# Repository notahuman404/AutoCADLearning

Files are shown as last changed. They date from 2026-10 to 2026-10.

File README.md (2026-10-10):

# Starbie

Starbie is a small motion-controlled digital pet built around a Seeed Studio XIAO ESP32-C3. It draws a one-bit pet on a 128×64 OLED, uses an MPU6050 to read tilt and shaking, and offers a four-way action menu. A DHT11 can provide temperature and humidity readings.

## Project images

<table>
  <tr>
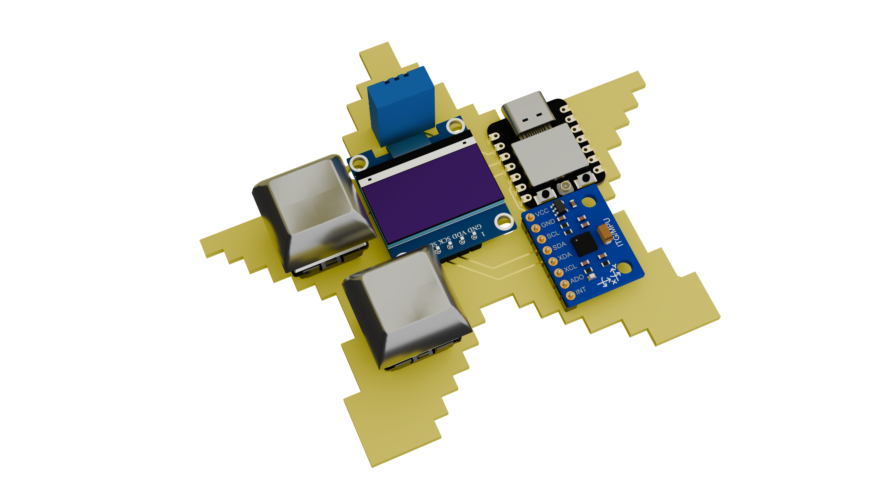
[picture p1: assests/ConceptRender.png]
Starbie concept render
    <td align="center"><strong>Concept render</strong><br></td>
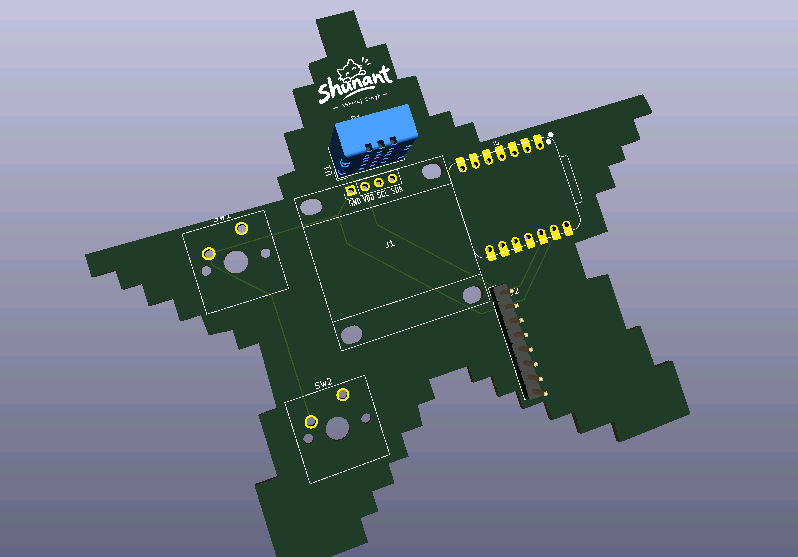
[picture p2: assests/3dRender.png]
Starbie PCB 3D render
    <td align="center"><strong>3D PCB render</strong><br></td>
  </tr>
  <tr>
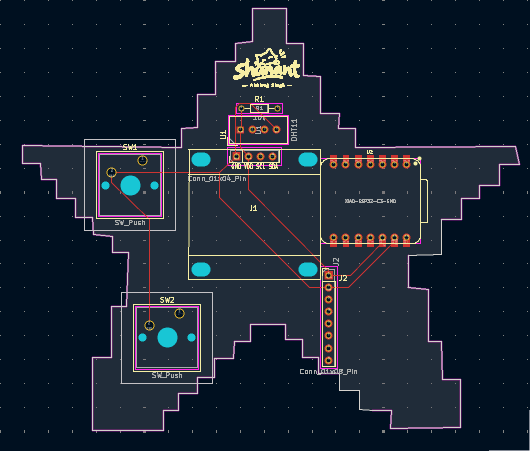
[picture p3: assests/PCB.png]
KiCad PCB layout
    <td align="center"><strong>PCB layout</strong><br></td>
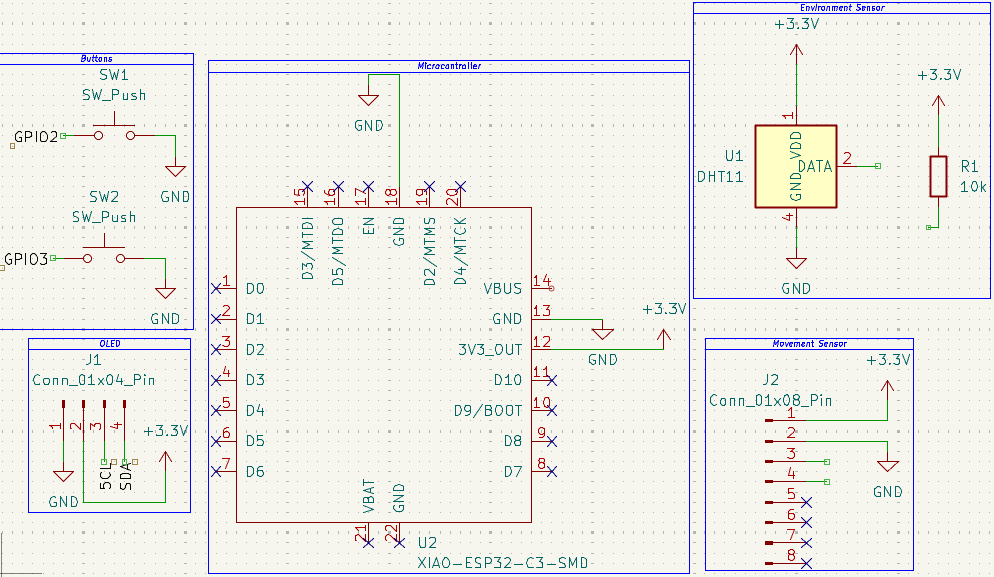
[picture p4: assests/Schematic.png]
KiCad schematic
    <td align="center"><strong>Schematic</strong><br></td>
  </tr>
</table>

## Features

- Animated pet with nap, play, feed, and pet actions.
- Tilt-controlled radial menu, using the MPU6050 as a simple air mouse.
- Shake reaction that wakes Starbie and changes its stats.
- Stats screen for joy, energy, fullness, and available sensor readings.
- Joy, energy, and fullness are saved using the ESP32 Preferences storage; stats do not drain while idle.

## Hardware

| Part | Role |
| --- | --- |
| Seeed Studio XIAO ESP32-C3 | Controller and firmware target |
| 0.96-inch 128×64 I²C OLED, SSD1306-compatible | Pet display |
| MPU6050 module (external via J2) | Tilt and shake sensing |
| DHT11 | Optional temperature and humidity sensing |
| 2 Cherry MX-compatible 1U switches | Menu/action and stats controls |
| 10 kΩ through-hole resistor | Listed as R1 in the schematic |
| Custom PCB | KiCad design in the starbie directory |

See BOM.csv for the current parts list. The guide pairs the XIAO ESP32-C3 symbol with the custom footprint ID `Imported Parts:XIAO-ESP32-C6-DIP`; the BOM preserves that assignment. The guide represents the MPU6050 module with a generic 1x08 connector: J2 is the board-mounted header and pins 1-4 carry +3.3V, GND, SCL, and SDA. The guide does not specify a particular breakout-board variant, so the BOM names it as an MPU6050 module connected via J2.

## Wiring

The firmware pin assignments are in Firmware/Starbie/Starbie.ino. OLED and MPU6050 share I²C.

| Device | XIAO connection | Notes |
| --- | --- | --- |
| OLED SDA | D4 / GPIO6 | I²C address defaults to 0x3C |
| OLED SCL | D5 / GPIO7 | Shared I²C bus |
| MPU6050 SDA | D4 / GPIO6 | I²C address defaults to 0x68 |
| MPU6050 SCL | D5 / GPIO7 | Shared I²C bus |
| DHT11 data | D1 / GPIO3 | Optional; set USE_DHT11 to false if not fitted |
| Button 1 | D2 / GPIO4 | Opens the menu; confirms the selected action |
| Button 2 | D3 / GPIO5 | Shows or hides the stats screen |

Connect module power and ground according to the module labels and the schematic. Verify voltage and pin order before powering the board.

## Firmware setup

1. Install Arduino IDE and add the Espressif ESP32 board package URL: https://espressif.github.io/arduino-esp32/package_esp32_index.json
2. Install the ESP32 board package by Espressif Systems and select XIAO_ESP32C3 under Tools → Board → esp32.
3. Install Adafruit GFX Library, Adafruit SSD1306, Adafruit MPU6050, and DHT sensor library. Accept the IDE's dependency prompts.
4. Open Firmware/Starbie/Starbie.ino, check the beginner settings and pin assignments, then upload to the XIAO ESP32-C3.

Button 1 opens the four-way menu. Tilt toward top for NAP, right for PLAY, bottom for FEED, or left for PET; press Button 1 again to confirm. Button 2 toggles stats. Shaking Starbie gives it a reaction and wakes it from a nap. The DHT11 can be disabled with USE_DHT11 if that sensor is not installed.

## Repository layout

- Firmware/Starbie/Starbie.ino — Arduino firmware.
- starbie/ — KiCad schematic, board, and project files.
- assests/ — project renders, schematic, and PCB images (the directory name is intentionally kept as it exists in the repository).
- 3D Models/ — STEP models for the display, switches, sensor module, and controller.
- Imported Parts.pretty/ — custom KiCad footprints.

## Reference

This project follows the [Starbie Week 1 guide](https://github.com/SharKingStudios/Starbie/blob/main/Week%201%20Guide.md).

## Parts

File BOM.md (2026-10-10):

# Starbie – bill of materials

<!-- Generated by Half Life from project cmuv3oycx0d7t01smc6fq98m5. Edits here are overwritten on the next sync. -->
<!-- Generated: 2026-10-10T05:16:34.077Z -->

> [!NOTE]
> This parts list is mirrored from [Half Life](https://halflife.hackclub.com). Editing it here will not change the platform's copy, and the next sync overwrites this file.

| Week | Tier | Parts funding |
| --- | --- | --- |
| Week 1 | Tier 1 | $30.00 |

| Part | What it's for | Qty | Unit | Total | Vendor |
| --- | --- | --- | --- | --- | --- |
| [Seeed Studio XIAO ESP32-C3](https://www.seeedstudio.com/Seeed-XIAO-ESP32C3-p-5431.html) | Main controller; firmware target | 1 | $4.90 | $4.90 | [Seeed Studio](https://www.seeedstudio.com/Seeed-XIAO-ESP32C3-p-5431.html) |
| [0.96-inch 128×64 SSD1306-compatible I²C OLED module](https://www.displaymodule.com/products/0-96-inch-oled-graphic-display-128x64-with-spi-i2c) | Displays the pet and menus | 1 | $4.90 | $4.90 | [DisplayModule](https://www.displaymodule.com/products/0-96-inch-oled-graphic-display-128x64-with-spi-i2c) |
| [DHT11 temperature/humidity sensor](https://shop.kincony.com/products/dht11-temperature-and-humidity-sensor) | temperature and humidity readings | 1 | $3.00 | $3.00 | [KinCony](https://shop.kincony.com/products/dht11-temperature-and-humidity-sensor) |
| [1×8, 2.54 mm vertical pin header](https://in.element14.com/molex/22-29-2081/conn-pin-hdr-8pos-1row-2-54mm/dp/1360136) | Board connector for the external motion-sensor module | 1 | $0.99 | $0.99 | [element14](https://in.element14.com/molex/22-29-2081/conn-pin-hdr-8pos-1row-2-54mm/dp/1360136) |
| [MX1A-51NN](https://www.mouser.in/en/ProductDetail/CHERRY/MX1A-51NN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) | Two user buttons | 2 | $1.23 | $2.46 | [Mouser](https://www.mouser.in/en/ProductDetail/CHERRY/MX1A-51NN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) |
| [MPU6050-6 Axis](https://rajivelectronics.com/product/mpu6050-triple-axis-gyro-accelerometer-module) | Tilt and shake sensing | 1 | $1.88 | $1.88 | [Rajiv Electronics](https://rajivelectronics.com/product/mpu6050-triple-axis-gyro-accelerometer-module) |
| [10 kΩ through-hole resistor](https://www.tanotis.com/products/genuine-sparkfun-resistor-10k-ohm-1-6th-watt-pth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) | it holds the data signal high when the sensor isn’t pulling it low | 1 | $0.15 | $0.15 | [Tanotis](https://www.tanotis.com/products/genuine-sparkfun-resistor-10k-ohm-1-6th-watt-pth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) |
| **Parts subtotal** | — | — | — | **$18.28** | — |
| **Tax & shipping** | — | — | — | **$0.00** | — |
| **Total** | — | — | — | **$18.28** | — |

$11.72 left of the tier's funding.

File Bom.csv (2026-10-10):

Reference | Quantity | Value | Footprint | Description
J1 | 1 | Conn_01x04_Pin | Imported Parts:Display_128x64_096_I2C | 0.96-inch 128x64 I2C OLED interface; firmware expects an SSD1306-compatible module
J2 | 1 | Conn_01x08_Pin | Connector_PinHeader_2.54mm:PinHeader_1x08_P2.54mm_Vertical | 1x8 2.54 mm vertical pin header
R1 | 1 | 10k | Resistor_THT:R_Axial_DIN0204_L3.6mm_D1.6mm_P7.62mm_Horizontal | 10 kΩ through-hole resistor
SW1 | 1 | SW_Push | Button_Switch_Keyboard:SW_Cherry_MX_1.00u_PCB | Cherry MX-compatible 1U momentary switch
SW2 | 1 | SW_Push | Button_Switch_Keyboard:SW_Cherry_MX_1.00u_PCB | Cherry MX-compatible 1U momentary switch
U1 | 1 | DHT11 | Sensor:Aosong_DHT11_5.5x12.0_P2.54mm | DHT11 temperature/humidity sensor
U2 | 1 | XIAO-ESP32-C3-SMD | Imported Parts:XIAO-ESP32-C6-DIP | Seeed Studio XIAO ESP32-C3 controller module
MPU6050 | 1 | MPU6050 | External module; connects through J2 (1x08) | Six-axis accelerometer/gyroscope module for tilt and shake sensing
PCB1 | 1 | Custom PCB | N/A (bare PCB) | Bare PCB fabricated from current KiCad board; Gerber files: Gerber-Files.zip

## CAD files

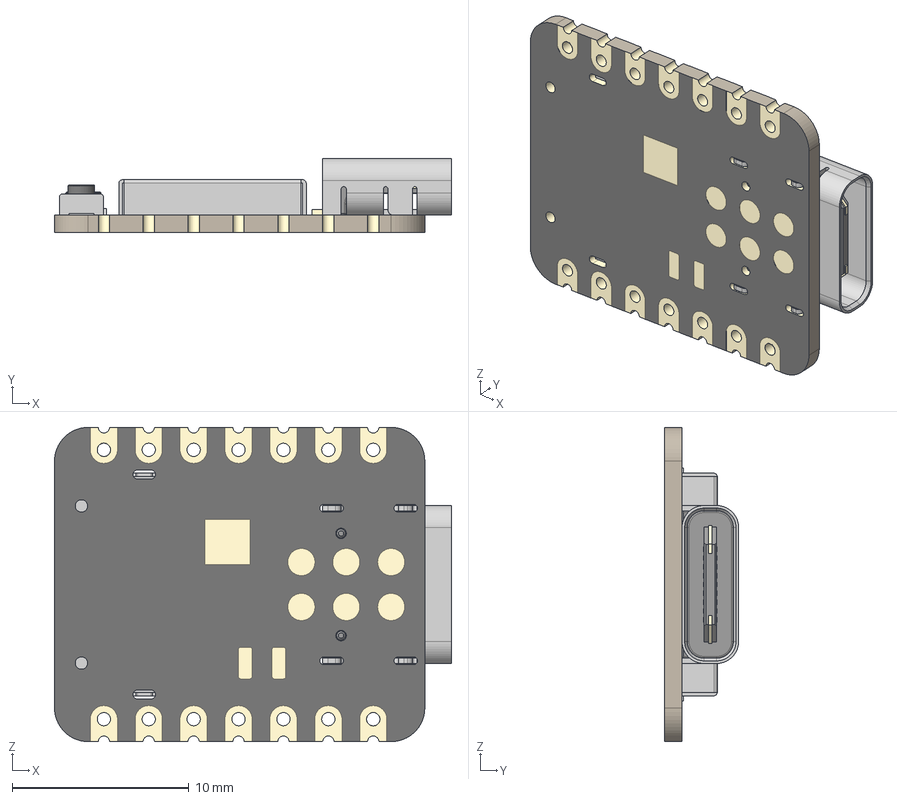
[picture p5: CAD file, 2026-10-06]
3D Models/Seeed Studio XIAO-ESP32-C3.step
22.5 x 4.21 x 17.8 mm
BOSS-EXTRUDE14_8_
BOSS-EXTRUDE7_4_
BOSS-EXTRUDE7_3_
BOSS-EXTRUDE14_4_
BOSS-EXTRUDE14_2_
BOSS-EXTRUDE14_11_
BOSS-EXTRUDE7_7_
BOSS-EXTRUDE14_9_
BOSS-EXTRUDE14_3_
BOSS-EXTRUDE14_7_
MIRROR2
BOSS-EXTRUDE14_5_
BOSS-EXTRUDE14_12_
BOSS-EXTRUDE7_8_
BOSS-EXTRUDE7_1_
BOSS-EXTRUDE14_10_
BOSS-EXTRUDE7_9_
BOSS-EXTRUDE14_6_
BOSS-EXTRUDE14_1_
BOSS-EXTRUDE7_6_
BOSS-EXTRUDE7_2_
CUT-EXTRUDE5
BOSS-EXTRUDE7_5_
U.FL Connector v1
Button (1) x 2
Shield

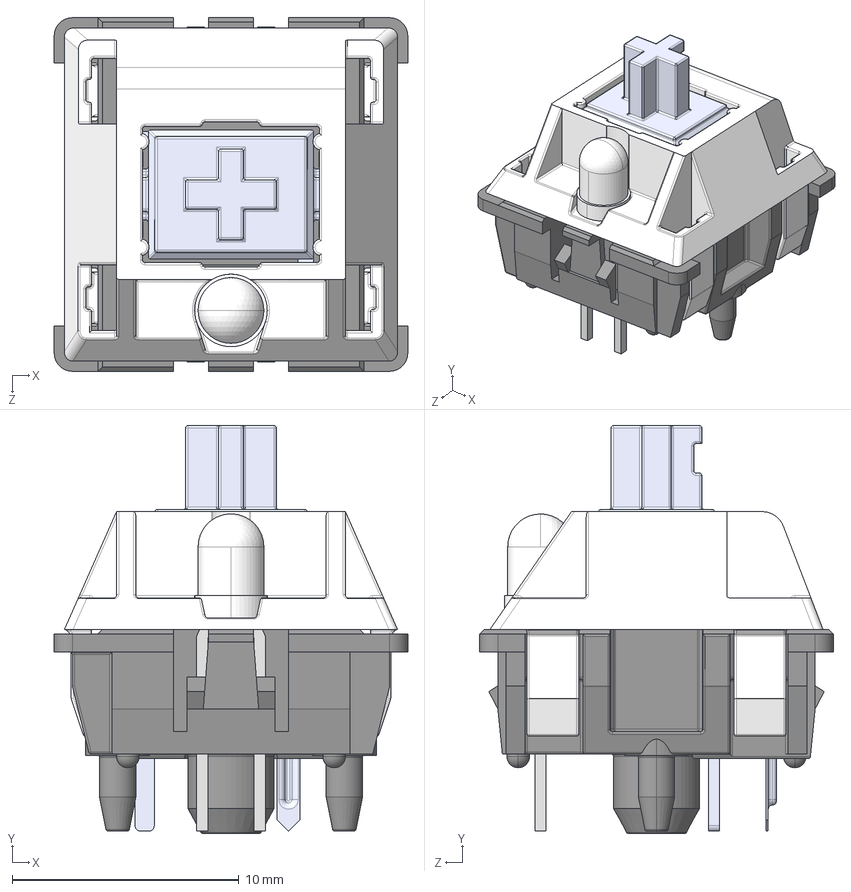
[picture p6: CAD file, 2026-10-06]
3D Models/Cherry MX.STEP
15.6 x 18.0 x 15.6 mm
Bottom
Pulsador
Top
Pieza5^Cherry MX
Pin1
Pin2
Led 3mm_trans

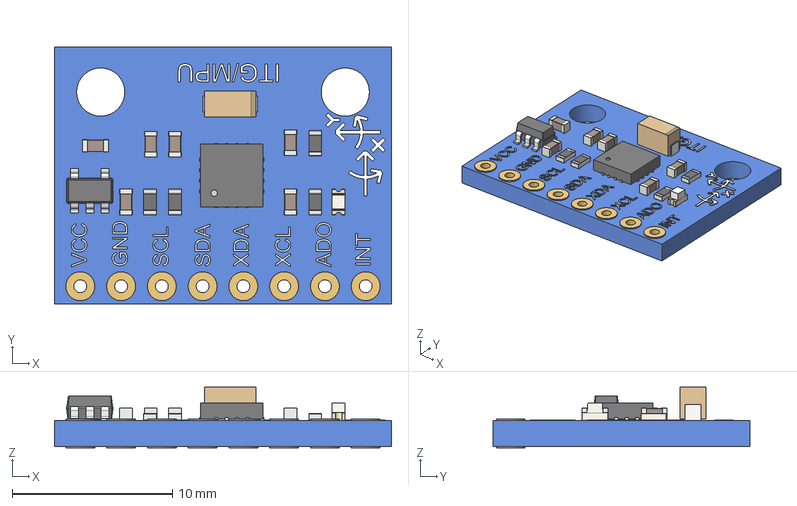
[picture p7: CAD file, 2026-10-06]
3D Models/GY-521_MPU6050 Accelerometer.step
21.0 x 16.0 x 3.80 mm
PCB
trou1
trou002
trou003
trou004
trou005
trou006
trou007
trou008
Text_X
Symb_Y
Symb_X
Text_Y
Text_VCC
Text_GND
Text_SCL
Text_SDA
Text_XDA
Text_XCL
Text_ADO
Text_INT
R_0603_1608Metric
R_0603_1608Metric001
R_0603_1608Metric002
R_0603_1608Metric003
C_0603_1608Metric
C_0603_1608Metric001
C_0603_1608Metric002
C_0603_1608Metric003
Corps002
Corps001 (Mirror #1)
C_0603_1608Metric004
C_0603_1608Metric005
LED_0603_1608Metric_Castellated
QFN_16_1EP_4x4mm_P065mm_EP21x21mm
Text_ITGMPU
SOT_23_5
Corps001

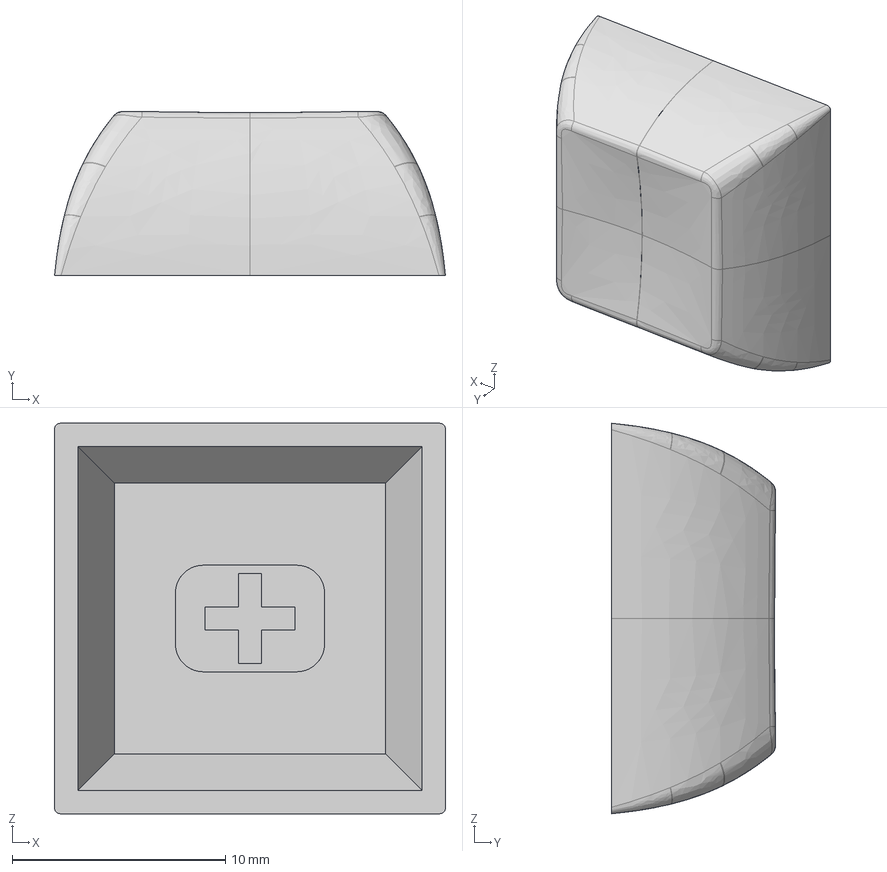
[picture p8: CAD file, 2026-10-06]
3D Models/DSA_Keycap_CherryMX.step
18.3 x 7.69 x 18.3 mm

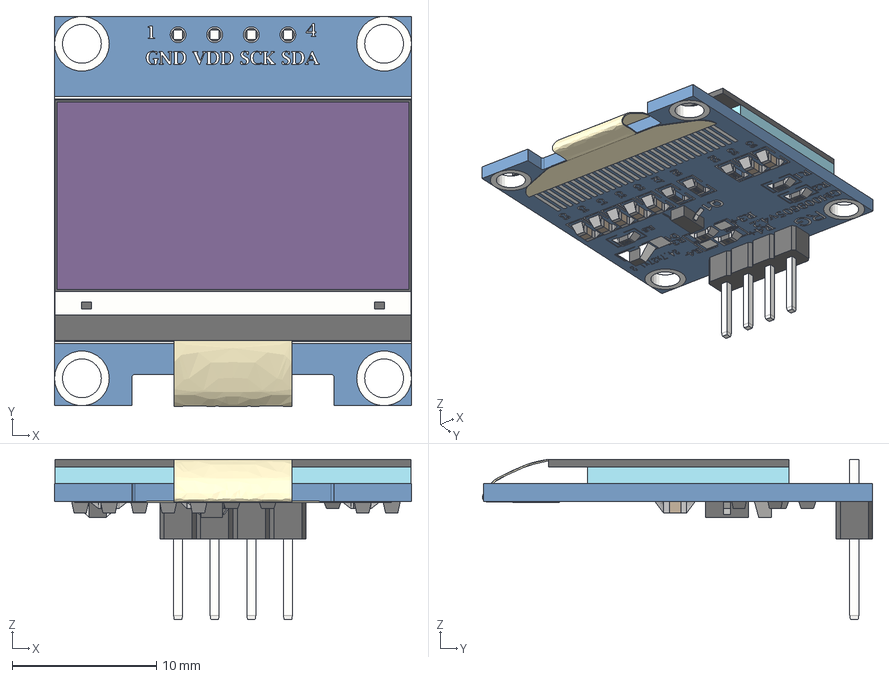
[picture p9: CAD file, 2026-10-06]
3D Models/0.96'' OLED Display.step
24.8 x 27.1 x 11.1 mm

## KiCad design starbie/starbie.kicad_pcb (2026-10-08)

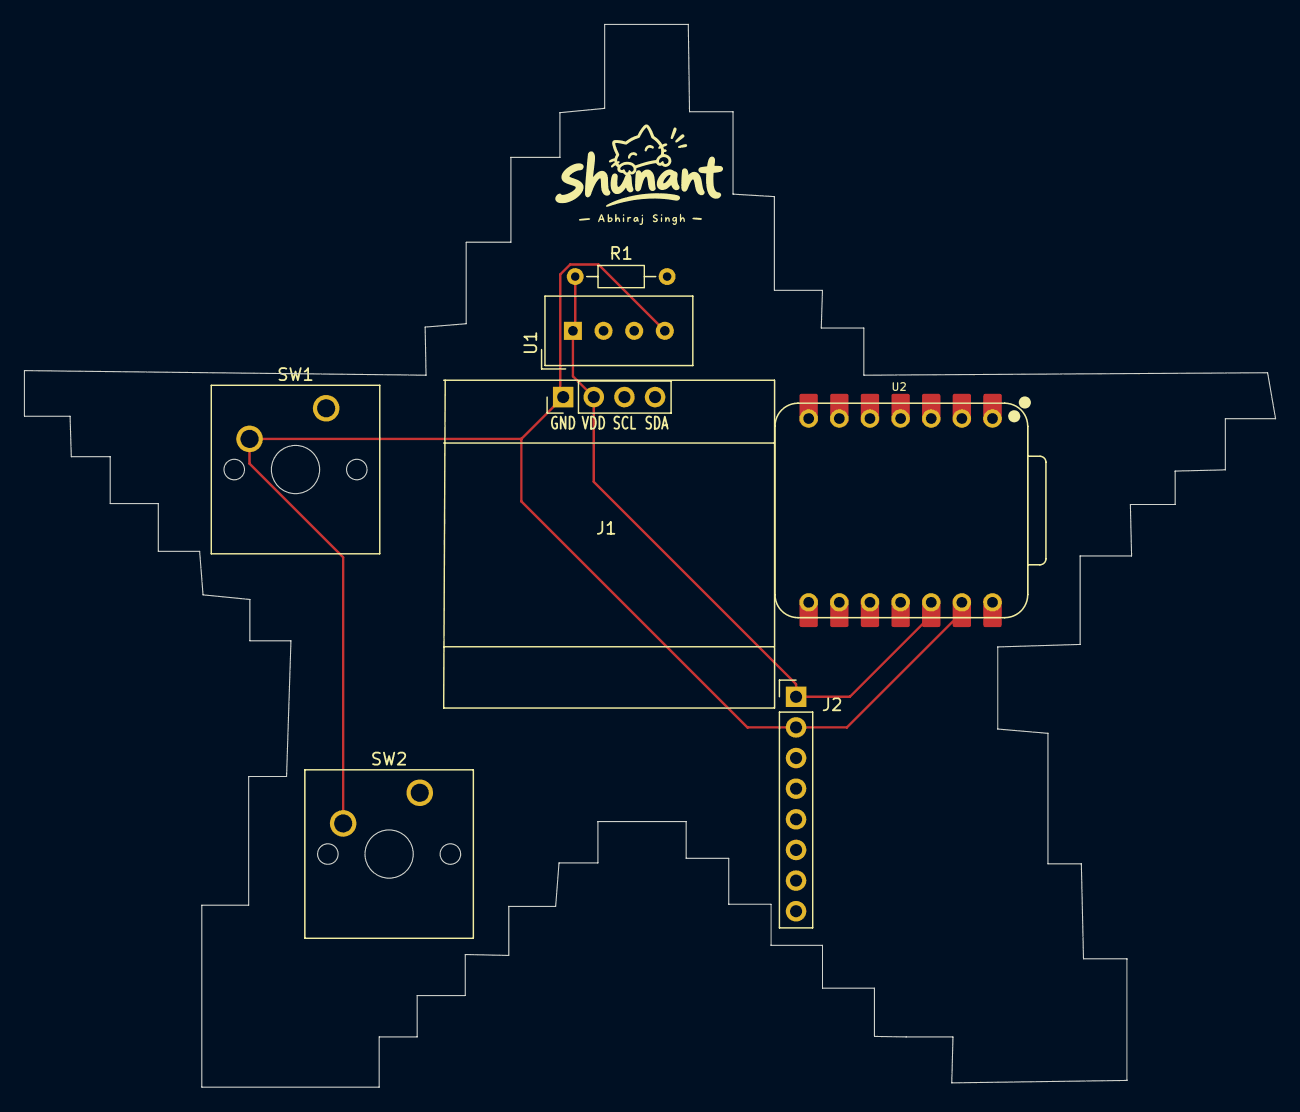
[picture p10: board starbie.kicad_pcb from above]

Board: 2 copper layers, 103.7 x 88.1 mm, 7 parts (0 on the bottom side), 2 nets.

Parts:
J1: Conn_01x04_Pin; Display_128x64_096_I2C
J2: Conn_01x08_Pin; PinHeader_1x08_P2.54mm_Vertical
R1: 10k; R_Axial_DIN0204_L3.6mm_D1.6mm_P7.62mm_Horizontal
SW1, SW2: SW_Push; SW_Cherry_MX_1.00u_PCB
U1: DHT11; Aosong_DHT11_5.5x12.0_P2.54mm
U2: XIAO-ESP32-C3-SMD; XIAO-ESP32-C6-DIP

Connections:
+3.3V: J1.2, J2.1, R1.1, U1.1 (VDD), U2.12 (3V3_OUT)
GND: J1.1, J2.2, SW1.2 (2_2), SW2.2 (2_2), U1.4 (GND), U2.13 (GND)

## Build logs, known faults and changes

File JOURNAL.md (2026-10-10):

# Starbie – devlog

<!-- Generated by Half Life from project cmuv3oycx0d7t01smc6fq98m5. Edits here are overwritten on the next sync. -->
<!-- Generated: 2026-10-10T08:19:58.287Z -->

> [!NOTE]
> This devlog is mirrored from [Half Life](https://halflife.hackclub.com). Editing it here will not change the platform's copy, and the next sync overwrites this file.

> A tiny motion-controlled digital pet, basically a desktop Tamagotchi. Totally not a Starboy.

| Week | Tier | Hours logged | Entries |
| --- | --- | --- | --- |
| Week 1 | Tier 1 | 7.5h | 5 |

## Contents

1. [2026-10-06 – I worked on the starbie project, My laptop is potato so I had to setup kicad on github codespace, which acted up often, I didn't include the time in log where is acted up. I mainly followed the tutori](#2026-10-06-i-worked-on-the-starbie-project-my-laptop-is-pota)
2. [2026-10-07 – So today I completed the PCB ROUTING! It took me a longer than expected because the its my first time trying to do the PCB routing. When converting to PCB editor I forgot to add footprints, then that](#2026-10-07-so-today-i-completed-the-pcb-routing-it-took-me-a)
3. [2026-10-08 – The tutorial had 2 errors in the footprints. Aside from that, in my own work there were around 8 more errors, all being the same that the shape is not closed. That's why that greyish color was not app](#2026-10-08-the-tutorial-had-2-errors-in-the-footprints-aside)
4. [2026-10-10 – I just completed everything in the STARBIE PROJECT!!!!!! SO this session was all about completing the README and the bom.csv file. Let me give a break down of where my time went in total this session](#2026-10-10-i-just-completed-everything-in-the-starbie-projec)
5. [2026-10-10 – FInally generated the Drill files and the Gerber files. Nothing in this journal I just generated the Gerber files and the drill files. Idk if this counts in the time in project, but i thought I should](#2026-10-10-finally-generated-the-drill-files-and-the-gerber-)

## Design

### 2026-10-06 – I worked on the starbie project, My laptop is potato so I had to setup kicad on github codespace, which acted up often, I didn't include the time in log where is acted up. I mainly followed the tutori

**2.5h**

I worked on the starbie project, My laptop is potato so I had to setup kicad on github codespace, which acted up often, I didn't include the time in log where is acted up. I mainly followed the tutorial. I know this shouldn't havetaken me this long, but acting up of codespace, then setting the codespace really burned through my time. It wont count towards my logged time but still it is the time I spent. Then in the tutorial, when I started building I noticed some green lines, it took me whole 30 minutes to find that to add those lines I just need to press W, then everything else went smoothly, though I had to retry this project 2 times before the third time I actually was able to build it. This mainly happened because absence of things like SW_PUSH type things in my kicad env, IDK why but it wasn't present, then i fixed the devcontainer because I had ai generated it, thn I again started and it worked. SO yeah... that sums everything up, yes Ik it is more time than you would expect one to take for task like this but you can check the GitHub repo and the dev container files, theirpushes to understadn my struggle

Screenshot 2026-10-06 6.54.20 PM

Screenshot 2026-10-06 6.18.36 PM

Screenshot 2026-10-06 6.50.21 PM

### 2026-10-07 – So today I completed the PCB ROUTING! It took me a longer than expected because the its my first time trying to do the PCB routing. When converting to PCB editor I forgot to add footprints, then that

**1.5h**

So today I completed the PCB ROUTING! It took me a longer than expected because the its my first time trying to do the PCB routing. When converting to PCB editor I forgot to add footprints, then that took a solid 5 minutes, ik very little time but it was the most frustruating time, otherwise everything went smoothly, I didn't run into much errors or anything, it went cools with me. It was kinda fun too. I learned something not mentioned in the tutorial, I can upload images and use it to trace out the shape, I didn't Google that up I promise! I discovered it by accident after I thought that the image button helps me add a prebuilt image, so I foolishly screenshoted the tutorial's image and added it there. I decide to stop and compete the project later as I am currently have caught a cold and fever and its draining the energy out of me. Bye! bye!



### 2026-10-08 – The tutorial had 2 errors in the footprints. Aside from that, in my own work there were around 8 more errors, all being the same that the shape is not closed. That's why that greyish color was not app

**1.5h**

The tutorial had 2 errors in the footprints. Aside from that, in my own work there were around 8 more errors, all being the same that the shape is not closed. That's why that greyish color was not appearing in my PCB layout, I had previously ignored it but then I realized it was actually because of an error, in fact many errors. Soo I started fixing them, first one went fine then second one and all the ones after that were for some reason locked, since I am still  <10 hours experience into kicad I didn't know what locked meant and how to remove it. I entered my issue in claude and it suggested to "Turn on the grid and snap" I pasted this actual thing copy pasted, I still don't know what that exactly means but the I found how to remove it totally by accident. I realized the ones I couldn't edit were purple for some reason. Then I started messing around and I wasn't able to select them, then I randomly saw the selection filter its felt somewhat similar to collision layer of Godot to me sooo I just went ahead and select each one of them thinking now selection should "collide with purple thingy". It worked I was able to select them, then I started messing with them clicking random buttons till I pressed L, I didn't catch it the first time like which specific key caused it but 5-10 minutes later it got clear to me how to lock and unlock things. Yeah!!! I know I am dumb for not knowing unable to finding these basics. But then the story of my stupidity continues, Just to clear one thing I am journaling this long because I ain't got nothing else to do so I am just writing each event that happened in the session so it is going to be a long one. SO Then I fixed the 8 errors I had introduced by my design and it made that faint grey color appear. Then for the sake of God I couldn't find how to fix the 2 errors showed in the tutorial, I just went ahead and messed around a bit longer, thought that it showed footprint, and that too with a specific component so I opened up the footprint editor and somehow even i don't remember but somehow opened the part that was showing error. Then I zoomed in and found it was basically open, since I was samiliar with open and closing of things like these because of the 8 errors I had fixed in the start design, I just went ahead and fixed it quite quickly, though layers was just me color matching the color of the outline of box with the options I got till I found the one which seemed the same. I removed and deleted the old line, thanked my old self for buying 100% keyboard which had the delete and end key, drew a new line and saved. I didn't know how to import this new design into the layout so i just thought it might auto import the updated version like an updated scene in Godot, closed the editor and hoped for best, when I opened the PCB editor and ran DRC it worked, IDK if that's the intended behaviour or not but stilllll, if it was working I was not gonna touch it. SO that was the journey of entire session



Screenshot 2026-10-08 10.13.31 AM

### 2026-10-10 – I just completed everything in the STARBIE PROJECT!!!!!! SO this session was all about completing the README and the bom.csv file. Let me give a break down of where my time went in total this session

**1.5h**

I just completed everything in the STARBIE PROJECT!!!!!! SO this session was all about completing the README and the bom.csv file. Let me give a break down of where my time went in total this session took me around 3 hours, but I am going to include the ones where I actually changed a file. So my time was mainly spent in the following things
1. Editing the README
2. Guiding replit on what to make
3. Making prompts
4. clicking images
In this the actual time I included was editing the README, So in the repo there are multiple changes to the README. Replit had created a branch where it kept adding junk content to the README instead of the actual content, like in place of MPU6050 it made the component Gyroscope, there were many other things, I fixed them manually in the replit env. and told it to push the updated content. Then I copied from its branch to the main branch and then  deleted the old branches to clean up the repo.  in the images there is a complete repo

Screenshot 2026-10-10 9.31.04 AM

Screenshot 2026-10-10 9.28.25 AM

I have also provided the 3d render of the project

3dRender
Idk what else images to attach as proof but I suppose these must be enough to prove what I worked on combined with the the commit history. One thing I worked on the README last night and committed it today and I was very much tired yesterday.

### 2026-10-10 – FInally generated the Drill files and the Gerber files. Nothing in this journal I just generated the Gerber files and the drill files. Idk if this counts in the time in project, but i thought I should

**0.5h**

FInally generated the Drill files and the Gerber files. Nothing in this journal I just generated the Gerber files and the drill files. Idk if this counts in the time in project, but i thought I should document everything so I added this log too

Screenshot 2026-10-10 1.48.14 PM

Screenshot 2026-10-10 1.46.40 PM

Screenshot 2026-10-10 1.48.52 PM

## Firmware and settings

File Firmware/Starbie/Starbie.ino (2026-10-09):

/*
  Starbie: a tiny motion-controlled digital pet

  This is intentionally one file. Open this .ino file in Arduino IDE, edit
  the BEGINNER SETTINGS section, and upload it to a Seeed XIAO ESP32-C3.

  Install these libraries with Sketch > Include Library > Manage Libraries:
    - Adafruit GFX Library
    - Adafruit SSD1306
    - Adafruit MPU6050
    - DHT sensor library
  Arduino IDE will offer to install their dependencies too. Click Install All.
*/

#include <Wire.h>
#include <Adafruit_GFX.h>
#include <Adafruit_SSD1306.h>
#include <Adafruit_MPU6050.h>
#include <DHT.h>
#include <Preferences.h>
#include <math.h>

// =========================== BEGINNER SETTINGS ===========================
// Everything most builders will want to customize is in this one section.

// --- Your board's pins ----------------------------------------------------
// These are ESP32-C3 GPIO numbers, with the XIAO pin labels beside them.
const int I2C_SDA_PIN = 6;       // XIAO D4: OLED + MPU6050 SDA
const int I2C_SCL_PIN = 7;       // XIAO D5: OLED + MPU6050 SCL
const int DHT_PIN = 3;           // XIAO D1: DHT11 data
const int BUTTON_ONE_PIN = 4;    // XIAO D2: opens/confirms the radial menu
const int BUTTON_TWO_PIN = 5;    // XIAO D3: shows/hides stats

// Set this to false if your submission does not have a DHT11.
const bool USE_DHT11 = true;

// Most parts use these addresses. Only change them if an I2C scanner says
// your part is different (common OLED alternative: 0x3D).
const uint8_t OLED_ADDRESS = 0x3C;
const uint8_t MPU6050_ADDRESS = 0x68;

// --- Starting stats -------------------------------------------------------
// Stats are 0 to 100. They only change when you select an action or shake
// Starbie; nothing slowly drains while it sits on your desk.
const int STARTING_JOY = 70;
const int STARTING_ENERGY = 75;
const int STARTING_FULLNESS = 65;

// Set true, upload once, then set it back to false if you want a fresh pet.
const bool RESET_SAVED_PET_ON_BOOT = false;

// --- Radial menu ----------------------------------------------------------
// These four actions appear at TOP, RIGHT, BOTTOM, then LEFT in the menu.
// The last word controls the matching little visual reaction.
enum PetReaction {
  NAP_REACTION,
  JUMP_REACTION,
  HEART_REACTION,
  RUN_REACTION,
};

struct MenuItem {
  const char *label;
  int joyChange;
  int energyChange;
  int fullnessChange;
  PetReaction reaction;
};

const MenuItem MENU_ITEMS[] = {
  {"NAP",   1,  18, -4, NAP_REACTION},   // top: sleep and emit Zs
  {"PLAY", 12, -9, -5, RUN_REACTION},    // right: two fast laps + hearts
  {"FEED",  3,  2,  18, JUMP_REACTION},  // bottom: wiggle and jump
  {"PET",   7,  0,  0, HEART_REACTION},  // left: jump and emit hearts
};
const int MENU_ITEM_COUNT = sizeof(MENU_ITEMS) / sizeof(MENU_ITEMS[0]);

// --- Movement feel --------------------------------------------------------
// Bigger MENU_TILT_LIMIT makes the menu ball move less.
const float MENU_TILT_LIMIT = 6.0f;

// MPU6050 orientation: change these settings instead of rewiring your board.
// 1. If the sensor is turned 90 degrees, set SWAP_MPU_AXES to true.
// 2. If a direction feels backwards, change that direction from 1.0f to -1.0f.
const bool SWAP_MPU_AXES = false;
const float MENU_X_DIRECTION = 1.0f;
const float MENU_Y_DIRECTION = -1.0f;

// A small dead zone makes the ball rest in the center until the board is tilted.
const float MENU_CENTER_DEADZONE = 0.8f;
const float SHAKE_THRESHOLD = 7.0f;

// Shake is the only movement that has an effect outside the radial menu.
const int SHAKE_JOY_CHANGE = 5;
const int SHAKE_ENERGY_CHANGE = -2;
const int SHAKE_FULLNESS_CHANGE = -1;

// --- Your pet's bitmap and animation -------------------------------------
// This is a simplified 32 by 32, one-bit version of the supplied character.
// You can replace it with your own art later; keep these size values matched
// to the sprite array you paste in.
const int PET_SPRITE_WIDTH = 32;
const int PET_SPRITE_HEIGHT = 32;

// The pet wanders unless it is asleep. A non-nap action does a tiny shake,
// then a jump, except PLAY which runs two fast laps.
const uint16_t PET_WALK_PIXEL_MS = 70;
const uint16_t PET_PRE_JUMP_MS = 230;
const uint16_t PET_JUMP_MS = 430;
const int PET_JUMP_HEIGHT = 16;
const uint32_t NAP_DURATION_MS = 48000;  // 48 seconds: four times the old nap.
const uint16_t HEARTS_DURATION_MS = 1600;
const uint16_t PLAY_LAP_MS = 800;
const uint8_t PLAY_LAP_COUNT = 2;

// Each byte stores eight pixels, left to right. This sparse outline keeps the
// supplied creature readable on a tiny, one-bit OLED: head, eye, legs, tail,
// and a small flower-like ear accent all stay separate instead of becoming a blob.
const uint8_t PROGMEM PET_SPRITE[] = {
  0x00, 0x00, 0x00, 0x00,
  0x00, 0x00, 0x00, 0x00,
  0x00, 0x00, 0x00, 0x00,
  0x00, 0x00, 0x00, 0x00,
  0x00, 0x00, 0x00, 0x00,
  0x00, 0x00, 0x00, 0x00,
  0x00, 0x70, 0x0a, 0x00,
  0x00, 0xf8, 0x1f, 0x00,
  0x00, 0x8c, 0x3f, 0x80,
  0x00, 0x43, 0xff, 0x00,
  0x00, 0x43, 0xff, 0x00,
  0x00, 0x30, 0x7e, 0x00,
  0x00, 0x98, 0x01, 0x00,
  0x01, 0x98, 0x01, 0x80,
  0x03, 0x00, 0x10, 0xc0,
  0x03, 0x04, 0x00, 0xc0,
  0x01, 0x8b, 0x01, 0x80,
  0x01, 0xcb, 0x03, 0x80,
  0x03, 0xc0, 0x03, 0xc0,
  0x03, 0xc0, 0x03, 0xc0,
  0x01, 0xc0, 0x03, 0x80,
  0x01, 0x80, 0x01, 0x80,
  0x00, 0x60, 0x06, 0x00,
  0x00, 0x3f, 0xfc, 0x00,
  0x00, 0x7f, 0xfe, 0x00,
  0x00, 0x70, 0x0e, 0x00,
  0x00, 0x00, 0x00, 0x00,
  0x00, 0x00, 0x00, 0x00,
  0x00, 0x00, 0x00, 0x00,
  0x00, 0x00, 0x00, 0x00,
  0x00, 0x00, 0x00, 0x00,
  0x00, 0x00, 0x00, 0x00,
};
// ===========================================================================
// You can read below without needing to understand every line. The rest of
// the sketch handles buttons, sensors, drawing, and saving automatically.

const int SCREEN_WIDTH = 128;
const int SCREEN_HEIGHT = 64;
const int MENU_CENTER_X = 64;
const int MENU_CENTER_Y = 32;
const int MENU_ITEM_X[] = {64, 108, 64, 20};
const int MENU_ITEM_Y[] = {12, 32, 53, 32};
const int MENU_BALL_X_RANGE = 37;
const int MENU_BALL_Y_RANGE = 22;
const uint16_t BUTTON_DEBOUNCE_MS = 30;
const uint16_t MPU_READ_INTERVAL_MS = 30;
const uint16_t DHT_READ_INTERVAL_MS = 2200;
const uint16_t SHAKE_COOLDOWN_MS = 650;
const float STANDARD_GRAVITY = 9.80665f;

Adafruit_SSD1306 display(SCREEN_WIDTH, SCREEN_HEIGHT, &Wire, -1);
Adafruit_MPU6050 mpu;
DHT dht(DHT_PIN, DHT11);
Preferences preferences;

struct PetState {
  int joy;
  int energy;
  int fullness;
};

struct ButtonState {
  int pin;
  bool stableState;
  bool lastRawState;
  uint32_t lastChangedAt;
};

enum View {
  PET_VIEW,
  MENU_VIEW,
  STATS_VIEW,
};

PetState pet = {STARTING_JOY, STARTING_ENERGY, STARTING_FULLNESS};
ButtonState buttonOne = {BUTTON_ONE_PIN, HIGH, HIGH, 0};
ButtonState buttonTwo = {BUTTON_TWO_PIN, HIGH, HIGH, 0};
View currentView = PET_VIEW;

bool mpuFound = false;
bool dhtFound = false;
float accelerationX = 0.0f;
float accelerationY = 0.0f;
float accelerationZ = STANDARD_GRAVITY;
float temperatureC = NAN;
float humidity = NAN;
float menuBallX = MENU_CENTER_X;
float menuBallY = MENU_CENTER_Y;
float menuCenterAccelerationX = 0.0f;
float menuCenterAccelerationY = 0.0f;
int selectedMenuItem = -1;
uint32_t lastMpuReadAt = 0;
uint32_t lastDhtReadAt = 0;
uint32_t lastShakeAt = 0;
uint32_t shakeAnimationEndsAt = 0;
uint32_t petJumpStartedAt = 0;
uint32_t nappingUntil = 0;
uint32_t heartAnimationEndsAt = 0;
uint32_t playRunStartedAt = 0;
int nappingPetX = 0;

int petWalkingX(uint32_t now);

int keepInRange(int value, int smallest, int largest) {
  return constrain(value, smallest, largest);
}

void changePet(int joyChange, int energyChange, int fullnessChange) {
  pet.joy = keepInRange(pet.joy + joyChange, 0, 100);
  pet.energy = keepInRange(pet.energy + energyChange, 0, 100);
  pet.fullness = keepInRange(pet.fullness + fullnessChange, 0, 100);
}

void loadPet() {
  preferences.begin("starbie", false);
  if (RESET_SAVED_PET_ON_BOOT) {
    preferences.clear();
  }
  pet.joy = preferences.getInt("joy", STARTING_JOY);
  pet.energy = preferences.getInt("energy", STARTING_ENERGY);
  pet.fullness = preferences.getInt("full", STARTING_FULLNESS);
}

void savePet() {
  preferences.putInt("joy", pet.joy);
  preferences.putInt("energy", pet.energy);
  preferences.putInt("full", pet.fullness);
}

void setUpButton(ButtonState &button) {
  pinMode(button.pin, INPUT_PULLUP);
  button.stableState = digitalRead(button.pin);
  button.lastRawState = button.stableState;
  button.lastChangedAt = millis();
}

// Returns true exactly once for each press, even if the switch bounces.
bool wasPressed(ButtonState &button) {
  const bool rawState = digitalRead(button.pin);
  const uint32_t now = millis();

  if (rawState != button.lastRawState) {
    button.lastRawState = rawState;
    button.lastChangedAt = now;
  }

  if (rawState != button.stableState &&
      now - button.lastChangedAt >= BUTTON_DEBOUNCE_MS) {
    button.stableState = rawState;
    return button.stableState == LOW;
  }

  return false;
}

void updateMpu() {
  if (!mpuFound || millis() - lastMpuReadAt < MPU_READ_INTERVAL_MS) {
    return;
  }
  lastMpuReadAt = millis();

  sensors_event_t acceleration;
  sensors_event_t gyro;
  sensors_event_t sensorTemperature;
  mpu.getEvent(&acceleration, &gyro, &sensorTemperature);
  accelerationX = acceleration.acceleration.x;
  accelerationY = acceleration.acceleration.y;
  accelerationZ = acceleration.acceleration.z;
}

void updateDht() {
  if (!dhtFound || millis() - lastDhtReadAt < DHT_READ_INTERVAL_MS) {
    return;
  }
  lastDhtReadAt = millis();

  const float newHumidity = dht.readHumidity();
  const float newTemperatureC = dht.readTemperature();
  if (!isnan(newHumidity)) {
    humidity = newHumidity;
  }
  if (!isnan(newTemperatureC)) {
    temperatureC = newTemperatureC;
  }
}

int petWalkingX(uint32_t now) {
  const int farthestX = SCREEN_WIDTH - PET_SPRITE_WIDTH;
  const uint32_t roundTrip = static_cast<uint32_t>(farthestX) * 2;
  const uint32_t step = (now / PET_WALK_PIXEL_MS) % roundTrip;
  return step <= farthestX ? step : roundTrip - step;
}

uint32_t playRunDuration() {
  return static_cast<uint32_t>(PLAY_LAP_MS) * PLAY_LAP_COUNT;
}

bool isNapping() {
  return nappingUntil != 0 && millis() < nappingUntil;
}

bool isPlaying() {
  return playRunStartedAt != 0 && millis() - playRunStartedAt < playRunDuration();
}

int playRunX(uint32_t now) {
  const int farthestX = SCREEN_WIDTH - PET_SPRITE_WIDTH;
  const uint32_t lapAge = (now - playRunStartedAt) % PLAY_LAP_MS;
  const float progress = static_cast<float>(lapAge) / PLAY_LAP_MS;
  return progress < 0.5f ? static_cast<int>(progress * 2.0f * farthestX)
                         : static_cast<int>((1.0f - progress) * 2.0f * farthestX);
}

void updatePetTimers() {
  if (nappingUntil != 0 && !isNapping()) {
    nappingUntil = 0;  // The pet wakes naturally when its nap time is over.
  }
  if (playRunStartedAt != 0 && !isPlaying()) {
    playRunStartedAt = 0;  // PLAY is exactly two left-to-right-to-left laps.
  }
}

// While the menu is open, the MPU6050 acts like a tiny air mouse. The position
// at the instant Button 1 opens the menu becomes the center for that menu use.
void updateMenuBall() {
  float xTilt = accelerationX - menuCenterAccelerationX;
  float yTilt = accelerationY - menuCenterAccelerationY;

  if (SWAP_MPU_AXES) {
    const float oldXTilt = xTilt;
    xTilt = yTilt;
    yTilt = oldXTilt;
  }
  xTilt = constrain(xTilt * MENU_X_DIRECTION, -MENU_TILT_LIMIT, MENU_TILT_LIMIT);
  yTilt = constrain(yTilt * MENU_Y_DIRECTION, -MENU_TILT_LIMIT, MENU_TILT_LIMIT);
  const float targetX = MENU_CENTER_X + (xTilt / MENU_TILT_LIMIT) * MENU_BALL_X_RANGE;
  const float targetY = MENU_CENTER_Y + (yTilt / MENU_TILT_LIMIT) * MENU_BALL_Y_RANGE;

  // This small amount of smoothing makes the ball feel less jittery.
  menuBallX += (targetX - menuBallX) * 0.20f;
  menuBallY += (targetY - menuBallY) * 0.20f;

  // The menu has four full sectors, not four tiny targets. Any tilt direction
  // past the center dead zone selects its matching top/right/bottom/left action.
  if (fabsf(xTilt) < MENU_CENTER_DEADZONE && fabsf(yTilt) < MENU_CENTER_DEADZONE) {
    selectedMenuItem = -1;
  } else if (fabsf(xTilt) > fabsf(yTilt)) {
    selectedMenuItem = xTilt > 0.0f ? 1 : 3;  // right or left
  } else {
    selectedMenuItem = yTilt > 0.0f ? 2 : 0;  // bottom or top
  }
}

void checkForShake() {
  if (!mpuFound || currentView != PET_VIEW) {
    return;
  }

  const float magnitude = sqrtf(accelerationX * accelerationX +
                                accelerationY * accelerationY +
                                accelerationZ * accelerationZ);
  const uint32_t now = millis();
  if (fabsf(magnitude - STANDARD_GRAVITY) >= SHAKE_THRESHOLD &&
      now - lastShakeAt >= SHAKE_COOLDOWN_MS) {
    lastShakeAt = now;
    nappingUntil = 0;  // A shake wakes a sleeping pet right away.
    shakeAnimationEndsAt = now + 350;
    changePet(SHAKE_JOY_CHANGE, SHAKE_ENERGY_CHANGE, SHAKE_FULLNESS_CHANGE);
    savePet();
  }
}

void openMenu() {
  currentView = MENU_VIEW;
  selectedMenuItem = -1;
  menuBallX = MENU_CENTER_X;
  menuBallY = MENU_CENTER_Y;
  // Calibrate here so every menu starts from however the builder is holding it.
  menuCenterAccelerationX = accelerationX;
  menuCenterAccelerationY = accelerationY;
}

void chooseMenuItem() {
  if (selectedMenuItem == -1) {
    return;  // Keep the menu open until the ball reaches a choice.
  }

  const MenuItem &item = MENU_ITEMS[selectedMenuItem];
  changePet(item.joyChange, item.energyChange, item.fullnessChange);
  savePet();
  const uint32_t now = millis();
  nappingUntil = 0;
  heartAnimationEndsAt = 0;
  playRunStartedAt = 0;

  if (item.reaction == NAP_REACTION) {
    petJumpStartedAt = 0;
    nappingPetX = petWalkingX(now);
    nappingUntil = now + NAP_DURATION_MS;
  } else if (item.reaction == RUN_REACTION) {
    petJumpStartedAt = 0;
    playRunStartedAt = now;
    heartAnimationEndsAt = now + playRunDuration();
  } else {
    // A confirmed action gets a little anticipation shake before the jump.
    petJumpStartedAt = now;
    if (item.reaction == HEART_REACTION) {
      heartAnimationEndsAt = now + HEARTS_DURATION_MS;
    }
  }
  currentView = PET_VIEW;
}

void handleButtons() {
  if (wasPressed(buttonOne)) {
    if (currentView == MENU_VIEW) {
      chooseMenuItem();
    } else {
      openMenu();
    }
  }

  if (wasPressed(buttonTwo)) {
    // Button 2 never changes the pet. It only lets you peek at the values.
    currentView = currentView == STATS_VIEW ? PET_VIEW : STATS_VIEW;
  }
}

void drawHeart(int x, int y) {
  // A tiny seven-pixel-wide heart that stays crisp on the OLED.
  display.fillRect(x - 2, y, 2, 2, SSD1306_WHITE);
  display.fillRect(x + 1, y, 2, 2, SSD1306_WHITE);
  display.fillRect(x - 3, y + 2, 7, 2, SSD1306_WHITE);
  display.fillRect(x - 2, y + 4, 5, 1, SSD1306_WHITE);
  display.fillRect(x - 1, y + 5, 3, 1, SSD1306_WHITE);
  display.drawPixel(x, y + 6, SSD1306_WHITE);
}

void drawHearts(uint32_t now, int petX, int petY) {
  if (now >= heartAnimationEndsAt) {
    return;
  }

  const float progress =
      1.0f - static_cast<float>(heartAnimationEndsAt - now) / HEARTS_DURATION_MS;
  const int rise = static_cast<int>(progress * 18.0f);
  drawHeart(petX + 10, petY - 3 - rise);
  drawHeart(petX + 22, petY - 9 - rise / 2);
}

void drawSleepZs(uint32_t now, int petX, int petY) {
  // The Zs float upward, then loop back down while the pet is napping.
  const int rise = static_cast<int>((now / 300UL) % 15UL);
  display.setTextSize(1);
  display.setTextColor(SSD1306_WHITE);
  display.setCursor(petX + 23, petY - 2 - rise);
  display.print("z");
  display.setCursor(petX + 28, petY - 8 - rise / 2);
  display.print("z");
}

void drawPet() {
  display.clearDisplay();

  const uint32_t now = millis();
  int petX = isNapping() ? nappingPetX : petWalkingX(now);
  if (isPlaying()) {
    petX = playRunX(now);
  }
  int petY = SCREEN_HEIGHT - PET_SPRITE_HEIGHT;

  // The pet always wanders except during a nap; PLAY temporarily takes over.
  if (now < shakeAnimationEndsAt) {
    petX += static_cast<int>(sinf(now / 18.0f) * 3.0f);
  }

  if (!isNapping() && petJumpStartedAt != 0) {
    const uint32_t animationAge = now - petJumpStartedAt;

    if (animationAge < PET_PRE_JUMP_MS) {
      petX += static_cast<int>(sinf(now / 16.0f) * 3.0f);
    } else if (animationAge < PET_PRE_JUMP_MS + PET_JUMP_MS) {
      const float jumpProgress =
          static_cast<float>(animationAge - PET_PRE_JUMP_MS) / PET_JUMP_MS;
      petY -= static_cast<int>(sinf(jumpProgress * PI) * PET_JUMP_HEIGHT);
    } else {
      petJumpStartedAt = 0;
    }
  }

  petX = constrain(petX, 0, SCREEN_WIDTH - PET_SPRITE_WIDTH);
  display.drawBitmap(petX, petY, PET_SPRITE, PET_SPRITE_WIDTH, PET_SPRITE_HEIGHT,
                     SSD1306_WHITE);

  if (isNapping()) {
    drawSleepZs(now, petX, petY);
  }
  drawHearts(now, petX, petY);
}

void drawMenuItem(int item) {
  const int boxWidth = 33;
  const int boxHeight = 12;
  const int boxX = MENU_ITEM_X[item] - boxWidth / 2;
  const int boxY = MENU_ITEM_Y[item] - boxHeight / 2;
  const bool isSelected = item == selectedMenuItem;

  if (isSelected) {
    display.fillRoundRect(boxX, boxY, boxWidth, boxHeight, 3, SSD1306_WHITE);
    display.setTextColor(SSD1306_BLACK);
  } else {
    display.drawRoundRect(boxX, boxY, boxWidth, boxHeight, 3, SSD1306_WHITE);
    display.setTextColor(SSD1306_WHITE);
  }

  display.setTextSize(1);
  const int labelLength = strlen(MENU_ITEMS[item].label);
  display.setCursor(MENU_ITEM_X[item] - labelLength * 3, MENU_ITEM_Y[item] - 3);
  display.print(MENU_ITEMS[item].label);
  display.setTextColor(SSD1306_WHITE);
}

void drawMenu() {
  display.clearDisplay();
  // The two diagonal lines divide the screen into four big selection sectors.
  display.drawLine(0, 0, SCREEN_WIDTH - 1, SCREEN_HEIGHT - 1, SSD1306_WHITE);
  display.drawLine(0, SCREEN_HEIGHT - 1, SCREEN_WIDTH - 1, 0, SSD1306_WHITE);
  for (int item = 0; item < MENU_ITEM_COUNT; item++) {
    drawMenuItem(item);
  }

  display.drawCircle(MENU_CENTER_X, MENU_CENTER_Y, 11, SSD1306_WHITE);
  display.fillCircle(static_cast<int>(menuBallX), static_cast<int>(menuBallY), 4,
                     SSD1306_WHITE);
}

void drawStatBar(int y, const char *label, int value) {
  display.setTextSize(1);
  display.setTextColor(SSD1306_WHITE);
  display.setCursor(4, y);
  display.print(label);
  display.drawRect(48, y, 57, 8, SSD1306_WHITE);
  display.fillRect(49, y + 1, map(value, 0, 100, 0, 55), 6, SSD1306_WHITE);
  display.setCursor(109, y);
  display.print(value);
}

void drawStats() {
  display.clearDisplay();
  drawStatBar(5, "JOY", pet.joy);
  drawStatBar(20, "ENERGY", pet.energy);
  drawStatBar(35, "FULL", pet.fullness);

  display.setCursor(4, 53);
  if (!isnan(temperatureC)) {
    display.print("TEMP ");
    display.print(static_cast<int>(temperatureC));
    display.print("C");
  } else {
    display.print("TEMP --");
  }

  display.setCursor(76, 53);
  if (!isnan(humidity)) {
    display.print("H ");
    display.print(static_cast<int>(humidity));
    display.print("%");
  } else {
    display.print("H --");
  }
}

void drawCurrentView() {
  if (currentView == MENU_VIEW) {
    drawMenu();
  } else if (currentView == STATS_VIEW) {
    drawStats();
  } else {
    drawPet();
  }
  display.display();
}

void setup() {
  Serial.begin(115200);
  Wire.begin(I2C_SDA_PIN, I2C_SCL_PIN);
  setUpButton(buttonOne);
  setUpButton(buttonTwo);
  loadPet();

  if (!display.begin(SSD1306_SWITCHCAPVCC, OLED_ADDRESS)) {
    Serial.println("OLED not found. Check power, GND, SDA, SCL, and address.");
    while (true) {
      delay(10);
    }
  }

  mpuFound = mpu.begin(MPU6050_ADDRESS, &Wire);
  if (mpuFound) {
    mpu.setAccelerometerRange(MPU6050_RANGE_8_G);
    mpu.setGyroRange(MPU6050_RANGE_500_DEG);
    mpu.setFilterBandwidth(MPU6050_BAND_21_HZ);
  } else {
    Serial.println("MPU6050 not found. The menu will not move until it is connected.");
  }

  if (USE_DHT11) {
    dht.begin();
    dhtFound = true;
  }

  drawCurrentView();
}

void loop() {
  updateMpu();
  updateDht();
  updatePetTimers();
  handleButtons();

  if (currentView == MENU_VIEW) {
    updateMenuBall();
  } else {
    checkForShake();
  }

  drawCurrentView();
  delay(16);  // Smooth display updates without making the code complicated.
}

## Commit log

2026-10-06 Correct devcontainer.json configuration
    Fixed JSON structure and ensured proper configuration for KiCad development environment.
2026-10-06 tried to follow the tutorial, codespace made it a nightmare
    [0.96'' OLED Display.step, Cherry MX.STEP, DSA_Keycap_CherryMX.step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]
2026-10-07 added the MPU6050 and OLED
    [starbie.kicad_pcb, starbie.kicad_sch]
2026-10-07 pushing progress to save it
    [starbie.kicad_pcb, starbie.kicad_sch]
2026-10-07 finshed pcb routing in odays session
    [starbie.kicad_pcb, starbie.kicad_sch]
2026-10-08 fixed the errors
    [starbie.kicad_pcb]
2026-10-08 added the logo to pcb
    [starbie.kicad_pcb]
2026-10-08 added arduino install script
2026-10-09 added the firmware code
    [starbie.kicad_pcb, starbie.kicad_sch]
2026-10-09 docs: add board BOM CSV
    [Bom.csv]
2026-10-10 added correct bom.csv content
    [Bom.csv]
2026-10-10 added the gerber amd drill files
    [starbie-B_Cu.gbr, starbie-B_Mask.gbr, starbie-B_Paste.gbr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]
